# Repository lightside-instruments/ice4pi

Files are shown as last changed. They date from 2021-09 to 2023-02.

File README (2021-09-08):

The clockinput4ultra96 is an open hardware extension module for Ultra96
or other 96boards CE compatible devices. It 

It has 2x SMA coaxial connectors for 1 sec PPS signal and 10 MHz clock
signal for frequency synchronization. Both are 50 Ohm terminated and
designed for 3.3V TTL signals.

Published by Lightside Instruments AS.

The design includes schematic and PCB design files for KiCAD.

The project is published by Lightside Instruments AS
under TAPR Open Hardware License. Read the LICENSE file
for details.

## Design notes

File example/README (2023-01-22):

Assuming you are running on a Raspberry Pi 2-4 or Zero (tested with bullseye):

1. Install all necessary packages to synthesize rot.v and build bit image (rot.bin) for the ice4pi:

 sudo apt-get install yosys fpga-icestorm arachne-pnr flashrom
 make

2. Make sure your Pi has SPI enabled (e.g. use raspi-config)

3. Load the rot.bin file to the shield:

 sudo make load

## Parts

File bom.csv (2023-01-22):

Reference | Quantity | Identifier | footprint | Value | Tolerance | Voltage | Current | Power | PN
U1 | 1 |  | Package_QFP:TQFP-144_20x20mm_P0.5mm |  |  |  |  |  | ICE40HX1K-TQ144
U2 | 1 |  | Package_SO:SOIC-8_3.9x4.9mm_P1.27mm |  |  |  |  |  | W25Q32JVSNIQ
R2;R16;R17;R15;R19;R18 | 6 |  | Resistor_SMD:R_0402_1005Metric | 10K |  |  |  |  | ERJ-2GEJ103X
C10;C29;C27;C6;C11;C13;C15 | 7 |  | Capacitor_SMD:C_0402_1005Metric | 0.01uF |  |  |  |  | 885012205012
C26;C18;C28;C19;C21;C23;C25;C24;C3;C9;C12;C14;C2 | 13 |  | Capacitor_SMD:C_0402_1005Metric | 0.1uF |  |  |  |  | 885012205037
C30;C16;C20;C1;C4 | 5 |  | Capacitor_SMD:C_0402_1005Metric | 10uF |  |  |  |  | ZRB15XR61A106ME01D
R20 | 1 |  | Resistor_SMD:R_0402_1005Metric | 100 |  |  |  |  | ERJ-2GEJ101X
D5 | 1 |  | LED_SMD:LED_0402_1005Metric | LED |  |  |  |  | 150040VS73240
U3 | 1 |  | Package_TO_SOT_SMD:SOT-23-5 | MIC5504-1.2YM5 |  |  |  |  | MIC5504-1.2YM5
C8 | 1 |  | Capacitor_SMD:C_0402_1005Metric | 4.7uF |  |  |  |  | C1005X5R0J475M050BC
U4 | 1 |  | Oscillator:Oscillator_SMD_Abracon_ASDMB-4Pin_2.5x2.0mm |  |  |  |  |  | DSC1001DE2-012.0000
C17;C22 | 2 |  | Capacitor_SMD:C_0402_1005Metric | 1 uF |  |  |  |  | 885012105012
J2 | 1 |  | ice4pi:PinSocket_2x20_P2.54mm_Vertical_1_04mm | Raspberry_Pi_2_3 |  |  |  |  | SSQ-120-03-T-D
J1 | 1 |  | ice4pi:PinSocket_2x06_P2.54mm_Vertical_1to6_7to12 | Pmod 2x6 |  |  |  |  | SSW-106-01-T-D
D6 | 1 |  | Diode_SMD:D_0603_1608Metric | CDBU0520 |  |  |  |  | CDBU0520
D4;D3;D2;D1 | 4 |  | LED_SMD:LED_0402_1005Metric | LED |  |  |  |  | 150040BS73240
R14;R13;R12;R11;R10 | 5 |  | Resistor_SMD:R_0402_1005Metric | 1K |  |  |  |  | ERJ-2GEJ102X

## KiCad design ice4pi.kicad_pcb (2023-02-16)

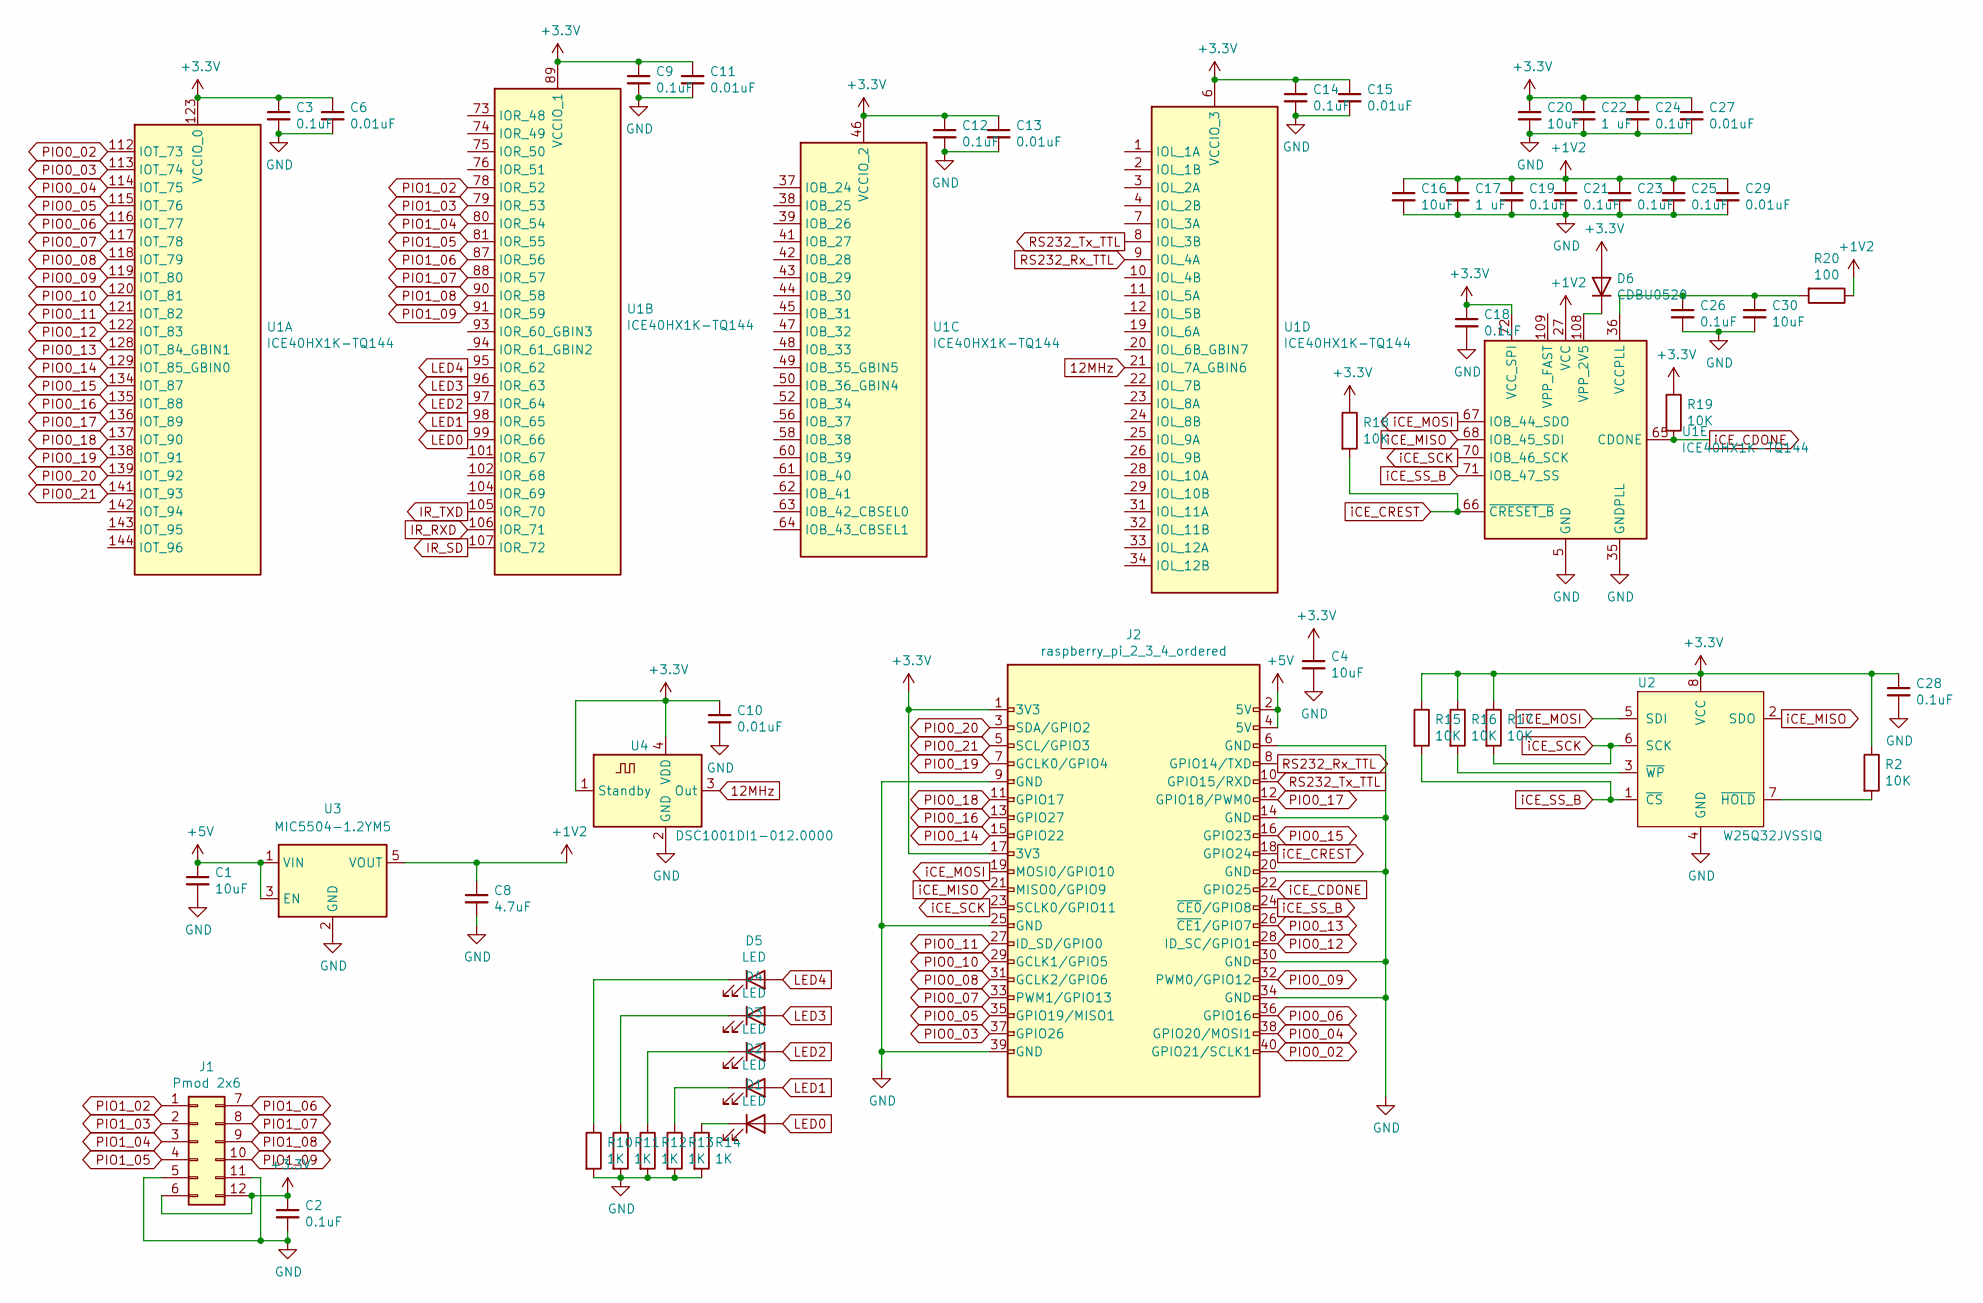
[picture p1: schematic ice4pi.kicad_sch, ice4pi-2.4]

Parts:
C1, C4, C16, C20, C30: 10uF; C_0402_1005Metric
C2, C3, C9, C12, C14, C18, C19, C21, C23, C24, C25, C26, C28: 0.1uF; C_0402_1005Metric
C6, C10, C11, C13, C15, C27, C29: 0.01uF; C_0402_1005Metric
C8: 4.7uF; C_0402_1005Metric
C17, C22: 1 uF; C_0402_1005Metric
D1, D2, D3, D4, D5: LED; LED_0402_1005Metric
D6: CDBU0520; D_0603_1608Metric
J1: Pmod 2x6; PinSocket_2x06_P2.54mm_Vertical_1to6_7to12
J2: raspberry_pi_2_3_4_ordered; PinSocket_2x20_P2.54mm_Vertical_1_04mm
R2, R15, R16, R17, R18, R19: 10K; R_0402_1005Metric
R10, R11, R12, R13, R14: 1K; R_0402_1005Metric
R20: 100; R_0402_1005Metric
U1: ICE40HX1K-TQ144; TQFP-144_20x20mm_P0.5mm
U2: W25Q32JVSSIQ; SOIC-8_3.9x4.9mm_P1.27mm
U3: MIC5504-1.2YM5; SOT-23-5
U4: DSC1001DI1-012.0000; Oscillator_SMD_Abracon_ASDMB-4Pin_2.5x2.0mm

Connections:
12MHz: U1.21 (IOL_7A_GBIN6), U4.3 (Out)
+1V2: C8.1, C16.1, C17.1, C19.1, C21.1, C23.1, C25.1, C29.1, R20.1, U1.27 (VCC), U1.51 (VCC), U1.92 (VCC), U1.111 (VCC), U3.5 (VOUT)
+3V3: C2.1, C3.1, C4.1, C6.1, C9.1, C10.1, C11.1, C12.1, C13.1, C14.1, C15.1, C18.1, C20.1, C22.1, C24.1, C27.1, C28.1, D6.2 (A), J1.6, J1.12, J2.1 (3V3), J2.17 (3V3), R2.1, R15.1, R16.1, R17.1, R18.1, R19.1, U1.6 (VCCIO_3), U1.30 (VCCIO_3), U1.46 (VCCIO_2), U1.57 (VCCIO_2), U1.72 (VCC_SPI), U1.89 (VCCIO_1), U1.100 (VCCIO_1), U1.123 (VCCIO_0), U1.133 (VCCIO_0), U2.8 (VCC), U4.1 (Standby), U4.4 (VDD)
+5V: C1.1, J2.2 (5V), J2.4 (5V), U3.1 (VIN), U3.3 (EN)
GND: C1.2, C2.2, C3.2, C4.2, C6.2, C8.2, C9.2, C10.2, C11.2, C12.2, C13.2, C14.2, C15.2, C16.2, C17.2, C18.2, C19.2, C20.2, C21.2, C22.2, C23.2, C24.2, C25.2, C26.2, C27.2, C28.2, C29.2, C30.2, J1.5, J1.11, J2.6 (GND), J2.9 (GND), J2.14 (GND), J2.20 (GND), J2.25 (GND), J2.30 (GND), J2.34 (GND), J2.39 (GND), R10.2, R11.2, R12.2, R13.2, R14.2, U1.5 (GND), U1.13 (GND), U1.14 (GND), U1.35 (GNDPLL), U1.59 (GND), U1.69 (GND), U1.86 (GND), U1.103 (GND), U1.132 (GND), U1.140 (GND), U2.4 (GND), U3.2 (GND), U4.2 (GND)
IR_RXD: U1.106 (IOR_71)
IR_SD: U1.107 (IOR_72)
IR_TXD: U1.105 (IOR_70)
LED0: D1.2 (A), U1.99 (IOR_66)
LED1: D2.2 (A), U1.98 (IOR_65)
LED2: D3.2 (A), U1.97 (IOR_64)
LED3: D4.2 (A), U1.96 (IOR_63)
LED4: D5.2 (A), U1.95 (IOR_62)
unnamed: C26.1, C30.1, R20.2, U1.36 (VCCPLL)
unnamed: D1.1 (K), R14.1
unnamed: D2.1 (K), R13.1
unnamed: D3.1 (K), R12.1
unnamed: D4.1 (K), R11.1
unnamed: D5.1 (K), R10.1
unnamed: D6.1 (K), U1.108 (VPP_2V5)
unnamed: R2.2, U2.7 (~HOLD)
unnamed: R16.2, U2.3 (~WP)
PIO0_02: J2.40 (GPIO21/SCLK1), U1.112 (IOT_73)
PIO0_03: J2.37 (GPIO26), U1.113 (IOT_74)
PIO0_04: J2.38 (GPIO20/MOSI1), U1.114 (IOT_75)
PIO0_05: J2.35 (GPIO19/MISO1), U1.115 (IOT_76)
PIO0_06: J2.36 (GPIO16), U1.116 (IOT_77)
PIO0_07: J2.33 (PWM1/GPIO13), U1.117 (IOT_78)
PIO0_08: J2.31 (GCLK2/GPIO6), U1.118 (IOT_79)
PIO0_09: J2.32 (PWM0/GPIO12), U1.119 (IOT_80)
PIO0_10: J2.29 (GCLK1/GPIO5), U1.120 (IOT_81)
PIO0_11: J2.27 (ID_SD/GPIO0), U1.121 (IOT_82)
PIO0_12: J2.28 (ID_SC/GPIO1), U1.122 (IOT_83)
PIO0_13: J2.26 (~CE1/GPIO7), U1.128 (IOT_84_GBIN1)
PIO0_14: J2.15 (GPIO22), U1.129 (IOT_85_GBIN0)
PIO0_15: J2.16 (GPIO23), U1.134 (IOT_87)
PIO0_16: J2.13 (GPIO27), U1.135 (IOT_88)
PIO0_17: J2.12 (GPIO18/PWM0), U1.136 (IOT_89)
PIO0_18: J2.11 (GPIO17), U1.137 (IOT_90)
PIO0_19: J2.7 (GCLK0/GPIO4), U1.138 (IOT_91)
PIO0_20: J2.3 (SDA/GPIO2), U1.139 (IOT_92)
PIO0_21: J2.5 (SCL/GPIO3), U1.141 (IOT_93)
PIO1_02: J1.1, U1.78 (IOR_52)
PIO1_03: J1.2, U1.79 (IOR_53)
PIO1_04: J1.3, U1.80 (IOR_54)
PIO1_05: J1.4, U1.81 (IOR_55)
PIO1_06: J1.7, U1.87 (IOR_56)
PIO1_07: J1.8, U1.88 (IOR_57)
PIO1_08: J1.9, U1.90 (IOR_58)
PIO1_09: J1.10, U1.91 (IOR_59)
RS232_Rx_TTL: J2.8 (GPIO14/TXD), U1.9 (IOL_4A)
RS232_Tx_TTL: J2.10 (GPIO15/RXD), U1.8 (IOL_3B)
iCE_CDONE: J2.22 (GPIO25), R19.2, U1.65 (CDONE)
iCE_CREST: J2.18 (GPIO24), R18.2, U1.66 (~CRESET_B)
iCE_MISO: J2.21 (MISO0/GPIO9), U1.68 (IOB_45_SDI), U2.2 (SDO)
iCE_MOSI: J2.19 (MOSI0/GPIO10), U1.67 (IOB_44_SDO), U2.5 (SDI)
iCE_SCK: J2.23 (SCLK0/GPIO11), R17.2, U1.70 (IOB_46_SCK), U2.6 (SCK)
iCE_SS_B: J2.24 (~CE0/GPIO8), R15.2, U1.71 (IOB_47_SS), U2.1 (~CS)

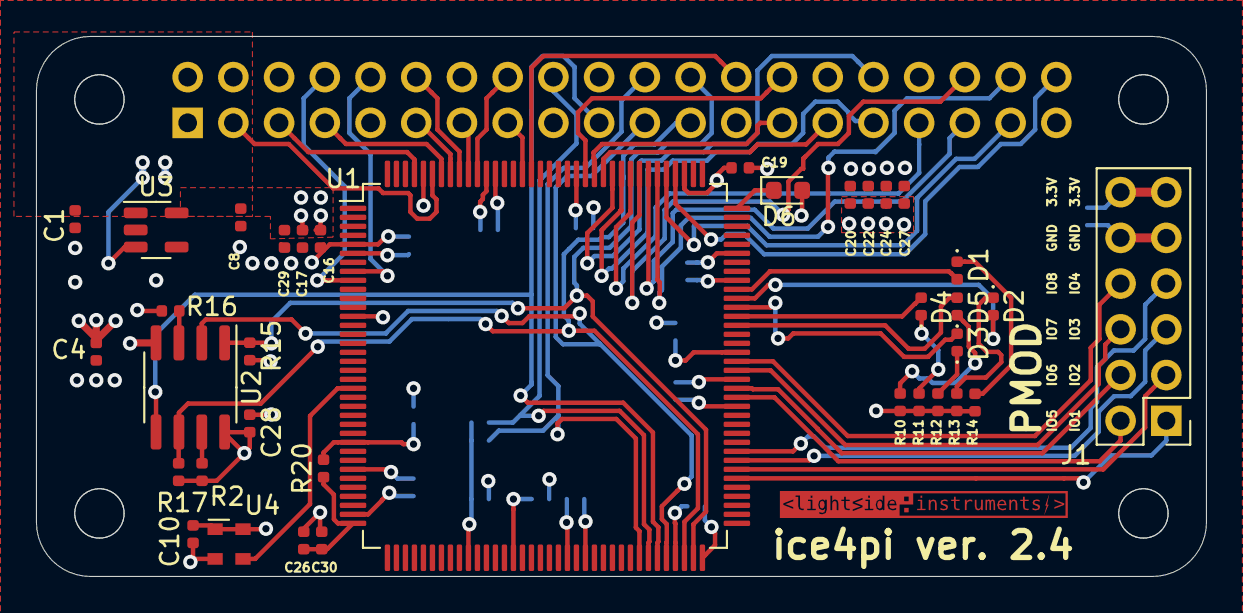
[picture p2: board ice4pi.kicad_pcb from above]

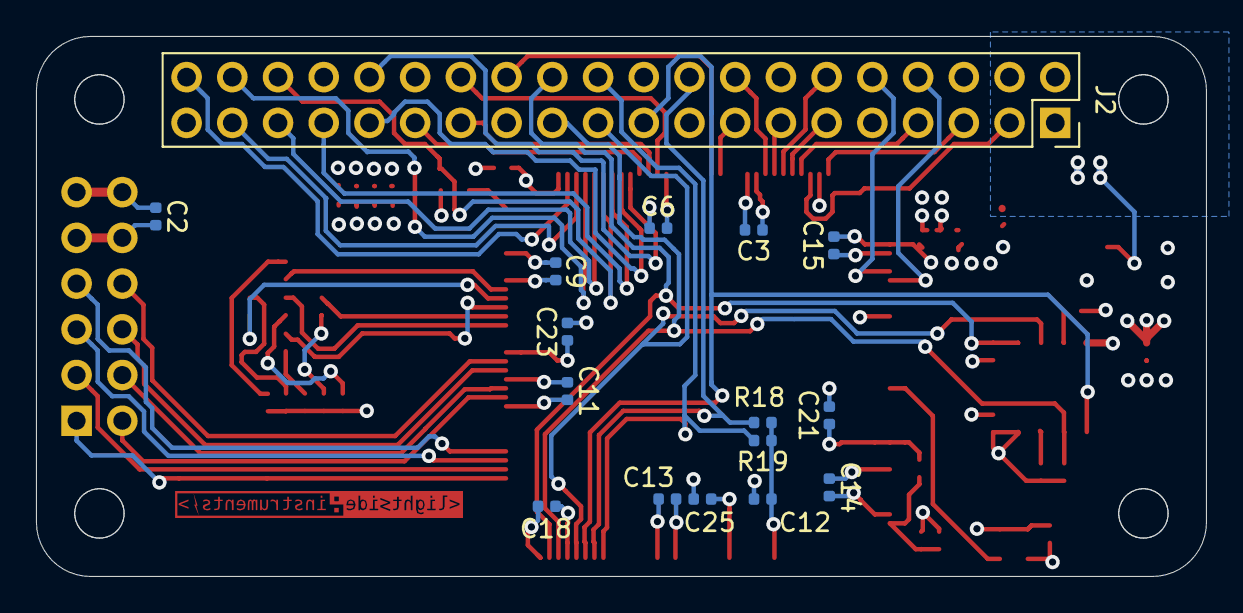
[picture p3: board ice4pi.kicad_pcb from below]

Board: 4 copper layers, 65.0 x 30.0 mm, 53 parts (16 on the bottom side), 55 nets.

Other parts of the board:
svg2mod: G***; lsi-logo-16mm-fcu

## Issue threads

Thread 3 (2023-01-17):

Explain what the example is going to do?

petterreinholdtsen, 2023-01-17:
It would be useful if the README in the example directory explain what the behaviour of the example should be.  I guess it should blink the LEDs on the top of the board, but am unsure as I do not get anything like that when compiling and loading the example.  This is the terminal output I get:

```
% make && sudo make load
yosys -q -p "synth_ice40 -blif rot.blif" rot.v
arachne-pnr -p rot.pcf rot.blif -o rot.txt
seed: 1
device: 1k
read_chipdb +/share/arachne-pnr/chipdb-1k.bin...
  supported packages: cb121, cb132, cb81, cm121, cm36, cm49, cm81, qn84, swg16tr, tq144, vq100
read_blif rot.blif...
prune...
read_pcf rot.pcf...
instantiate_io...
pack...

After packing:
IOs          6 / 96
GBs          0 / 8
  GB_IOs     0 / 8
LCs          65 / 1280
  DFF        29
  CARRY      23
  CARRY, DFF 0
  DFF PASS   5
  CARRY PASS 1
BRAMs        0 / 16
WARMBOOTs    0 / 1
PLLs         0 / 1

place_constraints...
promote_globals...
  promoted clk$2, 29 / 29
  promoted $abc$460$auto$rtlil.cc:1969:NotGate$402, 28 / 28
  promoted 2 nets
    1 sr/we
    1 clk
  2 globals
    1 sr/we
    1 clk
realize_constants...
  realized 1
place...
  initial wire length = 1022
  at iteration #50: temp = 9.13484, wire length = 452
  at iteration #100: temp = 3.81946, wire length = 357
  at iteration #150: temp = 1.44129, wire length = 174
  at iteration #200: temp = 0.0330434, wire length = 96
  final wire length = 96

After placement:
PIOs       4 / 96
PLBs       15 / 160
BRAMs      0 / 16

  place time 0.92s
route...
  pass 1, 0 shared.

After routing:
span_4     21 / 6944
span_12    7 / 1440

  route time 0.22s
write_txt rot.txt...
icebox_explain rot.txt > rot.ex
icepack rot.txt rot.bin
./ice4pi_prog rot.bin
4+0 oppføringer inn
4+0 oppføringer ut
4194304 byte (4,2 MB, 4,0 MiB) kopiert, 0,0959039 s, 43,7 MB/s
62+1 oppføringer inn
62+1 oppføringer ut
32220 byte (32 kB, 31 KiB) kopiert, 0,00150405 s, 21,4 MB/s
flashrom v1.2 on Linux 5.15.84-v7+ (armv7l)
flashrom is free software, get the source code at https://flashrom.org

Using clock_gettime for delay loops (clk_id: 1, resolution: 1ns).
Found Winbond flash chip "W25Q32.V" (4096 kB, SPI) on linux_spi.
Reading old flash chip contents... done.
Erasing and writing flash chip...
Warning: Chip content is identical to the requested image.
Erase/write done.
flashrom v1.2 on Linux 5.15.84-v7+ (armv7l)
flashrom is free software, get the source code at https://flashrom.org

Using clock_gettime for delay loops (clk_id: 1, resolution: 1ns).
Found Winbond flash chip "W25Q32.V" (4096 kB, SPI) on linux_spi.
Reading old flash chip contents... done.
Erasing and writing flash chip...
Warning: Chip content is identical to the requested image.
Erase/write done.
%

The only activity I see on the leds is that four of them turn on during flashing.

lightside-instruments, 2023-01-18:
Correct. This should work and you should see led blinking in a circle - 3 leds are on while one gets turned off in a clockwise rotation.

I will check if it is a software issue by reproducing the steps after apt update tomorrow. Will get back on this.

lightside-instruments, 2023-01-19:
I just retried the steps from scratch and it works. If not a hardware issue this might be some GPIO conflict. Are you sure there are no preinstalled applications attempting to access GPIOs etc.

Here are the package versions (just updated to the latest bullseye state) my test worked with:
```
yosys                                       0.9-1+b2
fpga-icestorm                         0~20190913git0ec00d8-2
fpga-icestorm-chipdb            0~20190913git0ec00d8-2
arachne-pnr                            0.1+20190728gitc40fb22-2
arachne-pnr-chipdb              0.1+20190728gitc40fb22-2
flashrom                                  1.2-5
```

petterreinholdtsen, 2023-01-19:
[lightside-instruments]
> I just retried the steps from scratch and it works. If not a hardware
> issue this might be some GPIO conflict. Are you sure there are no
> preinstalled applications attempting to access GPIOs etc.

Not sure at all.  The machine also have a pyjuice board connected for
power.  Perhaps the two are in each others hair?  Will try without the
pyjuice board.

--
Happy hacking
Petter Reinholdtsen

lightside-instruments, 2023-01-19:
pijuice uses only i2c pins so probably not the issue but do try without it in case there is some wierd powersupply correlation.

obviously the SPI connection and programming works since the verification is OK

If you see the LEDs changing intensity then then obviously they are driven from the FPGA ... so the question is why it stops.

The LEDs should turn on only when programming is finished and the iCE_CREST (pin 18) is released low to high transition. You could see very low intensity glow before programming is finished when the iCE_CREST is held down due to weak pullups.

lightside-instruments, 2023-01-19:
One suggestion:
```
diff --git a/example/ice4pi_prog b/example/ice4pi_prog
index c747db8..81f4aaa 100755
--- a/example/ice4pi_prog
+++ b/example/ice4pi_prog
@@ -1,5 +1,5 @@
 #!/bin/bash
-echo 24 > /sys/class/gpio/export
+echo 24 > /sys/class/gpio/export || true
 echo out > /sys/class/gpio/gpio24/direction
 echo 1 >/sys/class/gpio/gpio24/value
 sleep 1
@@ -10,6 +10,5 @@ dd if=${1} conv=notrunc of=image
 flashrom -p linux_spi:dev=/dev/spidev0.0,spispeed=20000 -w image
 #workaround first time fails after initial programming
 flashrom -p linux_spi:dev=/dev/spidev0.0,spispeed=20000 -w image
-echo in > /sys/class/gpio/gpio24/direction
-echo 24 > /sys/class/gpio/unexport
+echo 1 >/sys/class/gpio/gpio24/value
```

petterreinholdtsen, 2023-01-19:
[lightside-instruments]
> One suggestion:

I tested removing the pijuice hat without any changes.  The lights turn
on during flashing, but go dark once the flashing is done.

Tried your patch for ice4pi_prog, but it did not have any effect on the
light blinking

No clue what is wrong here.

One interesting thing is that the flashing claim the chip content is
identical to the requested image, even after I modified the .v file
slightly (changed the value used to compare to the divider by one).  I
expected this to create a different image for the flashing, but do not
really know what I am doing.

--
Happy hacking
Petter Reinholdtsen

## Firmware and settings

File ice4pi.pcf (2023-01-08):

# 5 LEDs  (identical to iCE40HX-1K iCEstick)
set_io D1 99
set_io D2 98
set_io D3 97
set_io D4 96
set_io D5 95

# 12MHz clock (identical to iCE40HX-1K iCEstick)
set_io clk 21

# pmod IO
set_io P1 78
set_io P2 79
set_io P3 80
set_io P4 81
set_io P5 87
set_io P6 88
set_io P7 90
set_io P8 91


#ice4pi Raspberry Pi 40-pin connector
#      R1  3V3
set_io R3  139
set_io R5  141
set_io R7  138
#      R9  GND
set_io R11 137
set_io R13 135
set_io R15 129
#      R17 3V3
set_io R19 67 #iCE_MOSI

set_io R21 68 #iCE_MISO
set_io R23 70 #iCE_SCK
#      R25 GND
set_io R27 121
set_io R29 120
set_io R31 118
set_io R33 117
set_io R35 115
set_io R37 113
#      R39 GND

#      R2   5V
#      R4   5V
#      R6  GND
set_io R8    9 # RS232_Rx_TTL
set_io R10   8 # RS232_Tx_TTL
set_io R12 136
#      R14 GND
set_io R16 134
set_io R18  66 # iCE_CREST

#      R20 GND
set_io R22  65 # iCE_DONE 
set_io R24  71 # iCE_SS_B
set_io R26 128
set_io R28 122
#      R30 GND
set_io R32 119
#      R34 GND
set_io R36 116
set_io R38 114
set_io R40 112

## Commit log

2021-01-31 Release ice4pi-spark-6x-sfp-1.2.1
    [bom.csv, ice4pi.kicad_pcb, ice4pi.sch]
2021-07-06 Release ice4ultra96-1.2-1
    [bom.csv, ice4pi.kicad_pcb, ice4pi.sch]
2021-07-06 Release ice4ultra96-1.2-2
    [bom.csv, ice4pi.kicad_pcb, ice4pi.sch]
2021-09-08 Release gpsclock4ultra96-1.0-1
    [bom.csv, ice4pi.kicad_pcb, ice4pi.sch]
2021-09-08 Release clockinput4ultra96-1.0-1
    [bom.csv, ice4pi.kicad_pcb, ice4pi.sch]
2022-02-08 Release ice4pi-2.0
    [bom.csv, ice4pi.kicad_pcb, ice4pi.sch]
2023-01-08 Release ice4pi-2.1
    [ice4pi.kicad_pcb, ice4pi.kicad_sch, ice4pi.sch]
2023-01-08 Release ice4pi-2.2
    [bom.csv, ice4pi.kicad_pcb, ice4pi.kicad_sch]
2023-01-22 Release ice4pi-2.3
    [bom.csv, ice4pi.kicad_pcb, ice4pi.kicad_sch]
2023-02-16 Release ice4pi-2.4
    [ice4pi.kicad_pcb, ice4pi.kicad_sch]
